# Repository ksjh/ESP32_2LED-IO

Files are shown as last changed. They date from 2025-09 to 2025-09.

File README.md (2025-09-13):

A simple LED I/O board based on an [ESP32-C6 Super Mini](https://www.espboards.dev/esp32/esp32-c6-super-mini/) that allows to switch two LEDs and read back the current status.
It is just a quick solution for [Lange Nacht der Wissenschaften 2025](https://nacht-der-wissenschaften.de/) created in an afternoon alongside with some simple Arduino code to control the LEDs via USB CDC and a 3D printed case.

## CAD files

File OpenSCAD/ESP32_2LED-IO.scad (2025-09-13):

part = "l2"; // c: case, l: lid, l2: thicker lid

// PCB size
pcbx = 47.5;
pcby = 26.5;
pcbz = 1.6;

pcbo = 1.0;

px = pcbx + pcbo;
py = pcby + pcbo;

fl = 1.2; // floor
wall = 1.2; // wall

// heat insert nut M3, L 4mm, OD 5mm
nutd = 4.4;
nuth = 5;
nutod = nutd + 2 * wall;

// total case size
sidex = nutod;
tx = px + 2 * sidex + 2 * wall;
ty = py + 2 * wall;
tz = 15;
caser = 4;

// standoff
sox = 3;
soz = nuth;
sod = 10;

// mounting screw
scx = 17.5;
scy = 7.5;
scd = 3.2;

// lid hole
hsx = 6.1;
hsy = 13.8;
hox = 4.19;
hoy = 10.62;

// USB connector
usbzl = fl + soz + pcbz;
usbx = 28;
usbsx = 10;
usbsz = 4;
usbsy = 7;

zf = 0.01;
$fn = 90;
pl = 0.2;

fl2 = fl + pl;

module rcube(x, y, z, r) {
  union() {
    translate([0, r, 0]) cube([x, y - 2 * r, z]);
    translate([r, 0, 0]) cube([x - 2 * r, y, z]);
    translate([r, r, 0]) cylinder(r=r, h=z);
    translate([r, y - r, 0]) cylinder(r=r, h=z);
    translate([x - r, r, 0]) cylinder(r=r, h=z);
    translate([x - r, y - r, 0]) cylinder(r=r, h=z);
  }
}

if (part == "c") {
  difference() {
    union() {
      difference() {
        rcube(tx, ty, tz, caser);
        translate([wall + sidex + sox, wall, fl])
          cube([px - 2 * sox, py, tz]);
        translate([wall + sidex, wall, fl + soz])
          cube([px, py, tz]);
        translate([wall, wall, tz - fl2])
          rcube(tx - 2 * wall, ty - 2 * wall, tz, caser - wall);
        translate([wall + nutod / 2, wall + nutod / 2, tz - fl2 - nuth])
          cylinder(d=nutd, h=tz);
        translate([tx - (wall + nutod / 2), wall + nutod / 2, tz - fl2 - nuth])
          cylinder(d=nutd, h=tz);
        translate([wall + nutod / 2, ty - (wall + nutod / 2), tz - fl2 - nuth])
          cylinder(d=nutd, h=tz);
        translate([tx - (wall + nutod / 2), ty - (wall + nutod / 2), tz - fl2 - nuth])
          cylinder(d=nutd, h=tz);
      }
      translate([wall + sidex + pcbo / 2 + scx, wall + pcbo / 2 + scy, 0])
        cylinder(d=sod, h=fl + soz);
    }
    translate([wall + sidex + pcbo / 2 + scx, wall + pcbo / 2 + scy, fl])
      cylinder(d=nutd, h=fl + soz);
    translate([wall + sidex + pcbo / 2 + usbx, ty - wall - zf, usbzl])
      cube([usbsx, wall + 2 * zf, tz]);
  }
} else if (part == "l2") {
  difference() {
    union() {
      rcube(tx, ty, fl, caser);  
      translate([wall + pl / 2, wall + pl / 2, 0])
        rcube(tx - 2 * wall - pl, ty - 2 * wall - pl, 2*fl, caser - wall - pl / 2);
      translate([tx - (wall + sidex + pcbo / 2 + usbx) - usbsx + pl / 2, ty - usbsy, 0])
        cube([usbsx - pl, usbsy, fl+tz - usbzl - usbsz]);
    }
    translate([wall + nutod / 2, wall + nutod / 2, -zf])
      cylinder(d=scd, h=2 * fl + 2 * zf);
    translate([tx - (wall + nutod / 2), wall + nutod / 2, -zf])
      cylinder(d=scd, h=2 * fl + 2 * zf);
    translate([wall + nutod / 2, ty - (wall + nutod / 2), -zf])
      cylinder(d=scd, h=2 * fl + 2 * zf);
    translate([tx - (wall + nutod / 2), ty - (wall + nutod / 2), -zf])
      cylinder(d=scd, h=2 * fl + 2 * zf);
    translate([tx - (wall + sidex + pcbo / 2 + hox) - hsx, wall + pcbo / 2 + hoy, -zf])
      cube([hsx, hsy, 2 * fl + 2 * zf]);
  }
}  else if (part == "l") {
  difference() {
    union() {
      translate([wall + pl / 2, wall + pl / 2, 0])
        rcube(tx - 2 * wall - pl, ty - 2 * wall - pl, fl, caser - wall - pl / 2);
      translate([tx - (wall + sidex + pcbo / 2 + usbx) - usbsx + pl / 2, ty - usbsy, 0])
        cube([usbsx - pl, usbsy, tz - usbzl - usbsz]);
    }
    translate([wall + nutod / 2, wall + nutod / 2, -zf])
      cylinder(d=scd, h=fl + 2 * zf);
    translate([tx - (wall + nutod / 2), wall + nutod / 2, -zf])
      cylinder(d=scd, h=fl + 2 * zf);
    translate([wall + nutod / 2, ty - (wall + nutod / 2), -zf])
      cylinder(d=scd, h=fl + 2 * zf);
    translate([tx - (wall + nutod / 2), ty - (wall + nutod / 2), -zf])
      cylinder(d=scd, h=fl + 2 * zf);
    translate([tx - (wall + sidex + pcbo / 2 + hox) - hsx, wall + pcbo / 2 + hoy, -zf])
      cube([hsx, hsy, fl + 2 * zf]);
  }
}

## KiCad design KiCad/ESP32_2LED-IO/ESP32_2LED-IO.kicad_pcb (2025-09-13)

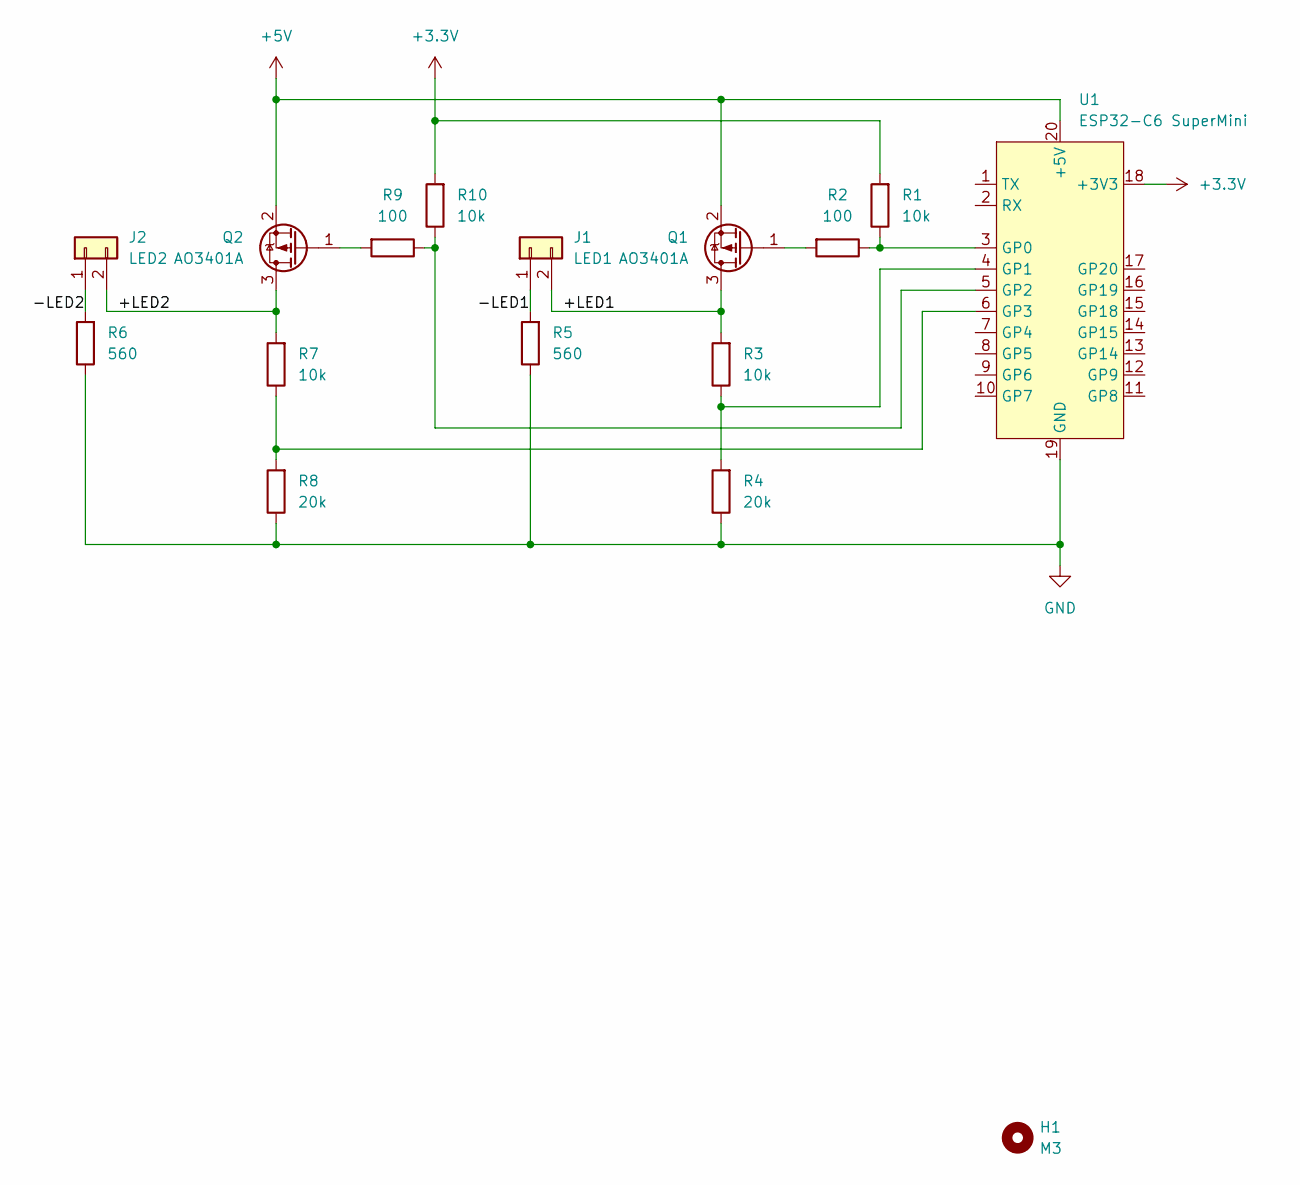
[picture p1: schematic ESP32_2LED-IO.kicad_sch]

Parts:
H1: M3; MountingHole_3.2mm_M3
J1: LED1; Molex_KK-254_AE-6410-02A_1x02_P2.54mm_Vertical
J2: LED2; Molex_KK-254_AE-6410-02A_1x02_P2.54mm_Vertical
Q1, Q2: AO3401A; SOT-23
R1, R3, R7, R10: 10k; R_0603_1608Metric_Pad0.98x0.95mm_HandSolder
R2, R9: 100; R_0603_1608Metric_Pad0.98x0.95mm_HandSolder
R4, R8: 20k; R_0603_1608Metric_Pad0.98x0.95mm_HandSolder
R5, R6: 560; R_1206_3216Metric_Pad1.30x1.75mm_HandSolder
U1: ESP32-C6 SuperMini; ESP32C6-SuperMini-SMD

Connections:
+3.3V: R1.2, R10.2, U1.18 (+3V3)
+5V: Q1.2 (S), Q2.2 (S), U1.20 (+5V)
/+LED1: J1.2, Q1.3 (D), R3.2
/+LED2: J2.2, Q2.3 (D), R7.2
/-LED1: J1.1, R5.2
/-LED2: J2.1, R6.2
GND: R4.1, R5.1, R6.1, R8.1, U1.19 (GND)
unnamed: Q1.1 (G), R2.2
unnamed: Q2.1 (G), R9.2
unnamed: R1.1, R2.1, U1.3 (GP0)
unnamed: R3.1, R4.2, U1.4 (GP1)
unnamed: R9.1, R10.1, U1.5 (GP2)
unnamed: R7.1, R8.2, U1.6 (GP3)

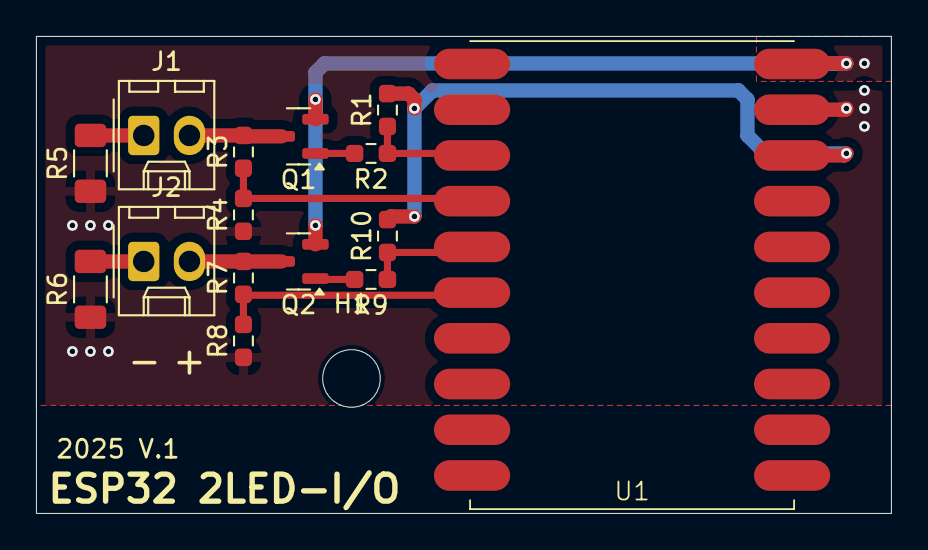
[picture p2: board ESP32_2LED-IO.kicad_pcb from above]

Board: 2 copper layers, 47.5 x 26.5 mm, 16 parts (0 on the bottom side), 13 nets.

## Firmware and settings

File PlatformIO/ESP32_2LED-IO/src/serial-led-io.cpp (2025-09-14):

#include <arduino.h>
#include "serial-led-io.h"

int schi;
uint8_t sled, rled;

void setup()
{
    pinMode(LED1OUT, OUTPUT);
    digitalWrite(LED1OUT, LEDOFF);
    pinMode(LED2OUT, OUTPUT);
    digitalWrite(LED2OUT, LEDOFF);
    pinMode(LED1STAT, INPUT);
    pinMode(LED2STAT, INPUT);
}

void loop()
{
    while (Serial && Serial.available())
    {
        schi = Serial.read();
        if (schi >= '0' && schi < '4')
        {
            sled = (uint8_t)(schi - '0');
            setleds(sled);
        }
        rled = getleds();
        if (Serial && Serial.availableForWrite())
            Serial.write(char('0' + rled));
    }
}

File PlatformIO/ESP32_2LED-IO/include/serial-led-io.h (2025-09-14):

#ifndef SERIAL_LED_IO_H_
#define SERIAL_LED_IO_H_

#define LED1OUT  0
#define LED1STAT 1
#define LED2OUT  2
#define LED2STAT 3

#define LEDON    LOW
#define LEDOFF   HIGH

void setleds(uint8_t status);
uint8_t getleds();

void setleds(uint8_t status)
{
    if (status & 0x01)
        digitalWrite(LED1OUT, LEDON);
    else
        digitalWrite(LED1OUT, LEDOFF);
    if (status & 0x02)
        digitalWrite(LED2OUT, LEDON);
    else
        digitalWrite(LED2OUT, LEDOFF);
}

uint8_t getleds()
{
    uint8_t status = 0;
    if (digitalRead(LED1STAT) == HIGH)
        status |= 0x1;
    if (digitalRead(LED2STAT) == HIGH)
        status |= 0x2;
    return status;
}

#endif // SERIAL_LED_IO_H_

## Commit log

2025-09-13 Add licenses for exported KiCad symbols and footprints
2025-09-13 Fix OpenSCAD variable order
    [ESP32_2LED-IO.scad]
2025-09-13 Add optional thicker lid
    [ESP32_2LED-IO.scad]
2025-09-14 Arduino code cleanup
